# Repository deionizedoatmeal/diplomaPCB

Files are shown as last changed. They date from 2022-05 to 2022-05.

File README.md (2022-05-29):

### Bill of Materials:
Parts for the board:
| Part | Quantity | Package | Value | Link |
| --- |:---:|:---:|:---:|:---:|
| Microprocessor | 1 | QFN-56 | RP2040 | |
| 8MB SPI Flash  | 1 | SOIC-8 | | |
| NeoPixel LED | 37 | 1515 LED | SK6805-E-J | [Adafruit](https://www.adafruit.com/product/4492) |
| 7 Segement LED | 4 | LTS6760 | Common Cathode | | 
| Button Switch  | 5 | KMR2 | Momentary | |
| Schottky Diode | 4 | SOD-123 | MBR0540 | |
| Transistor | 14 | SOT-23 | | |
| Crystal | 1 | 2.5mm X 2.0mm | 12.000 MHz | |
| I2C Quad ADC | 8 | SOIC-16 | PCF8591 | |
| Quad Logic Shifter | 1 | SOIC-16 | 74AHCT125 | |
| Voltage Regulator | 4 | SOT-23-5 | AP2112K-3.3 | |
| USB-C Receptacle | 5 | SMD | | |
| USB-C Plug | 4 | SMD Edge Launch  | | [Adafruit](https://www.adafruit.com/product/4932) [Digikey](https://www.digikey.com/en/products/detail/adafruit-industries-llc/4932/13997774) |
| Resistor | 23 | 0603/1608 Metric | 300 Ω | |
| Resistor | 10 | 0603/1608 Metric | 1 kΩ | |
| Resistor | 2 | 0603/1608 Metric | 5.11 kΩ | |
| Resistor | 60 | 0603/1608 Metric | 10 kΩ | |
| Resistor | 9 | 0603/1608 Metric | 1 MΩ | |
| Resistor | 2 | 0402/1005 Metric | 27 Ω | |
| Capacitor | 45 | 0805/2012 Metric | 0.1 µF | |
| Capacitor | 20 | 0085/2012 Metric | 10 µF | |
| Capacitor | 2 | 0402/1005 Metric | 27 pF | |
| Capacitor | 10 | 0402/1005 Metric | 100 nF | |
| Capacitor | 2 | 0402/1005 Metric | 1 µF | |
| Magnets | 112 | 3mm diameter x 1mm | Neodymium | |

Parts for the game pieces (assuming 20 pieces for each nationality):
| Part | Quantity | Package | Value | Link |
| --- |:---:|:---:|:---:|:---:|
| Resistor | 20 | Through Hole | 60 kΩ | |
| Resistor | 20 | Through Hole | 25 kΩ | |
| Resistor | 20 | Through Hole | 13.4 kΩ | |
| Resistor | 20 | Through Hole | 7.5 kΩ | |
| Resistor | 20 | Through Hole | 4 kΩ | |
| Resistor | 20 | Through Hole | 1.7 kΩ | |
| Resistor | 20 | Through Hole | 0 Ω | |
| Magnets | 140 | 3mm diameter x 1mm | Neodymium | |
| Pogo Pins | 140 | anything that makes good contact with 2mm diameter pads and fits inside the piece | | [Digikey](https://www.digikey.com/en/products/detail/mill-max-manufacturing-corp/0965-0-15-20-80-14-11-0/2784013) |

### 3D Printing Pieces:

### Assembly Instructions:

### Software Install Instructions:
1) Hold down boot button on underside while plugging USB into computer.
2) When the `RPI-RP2` device shows up, copy [Adafruit's CircuitPython library](https://circuitpython.org/board/adafruit_feather_rp2040/) to the volume. 
3) Wait for the device to disappear and reappear as `CURCUITPY`, then copy all the libraries into the `lib` directory on the RP2040.
4) Finally, copy `code.py` into the `CURCUITPY` volume.

### Images
PCB

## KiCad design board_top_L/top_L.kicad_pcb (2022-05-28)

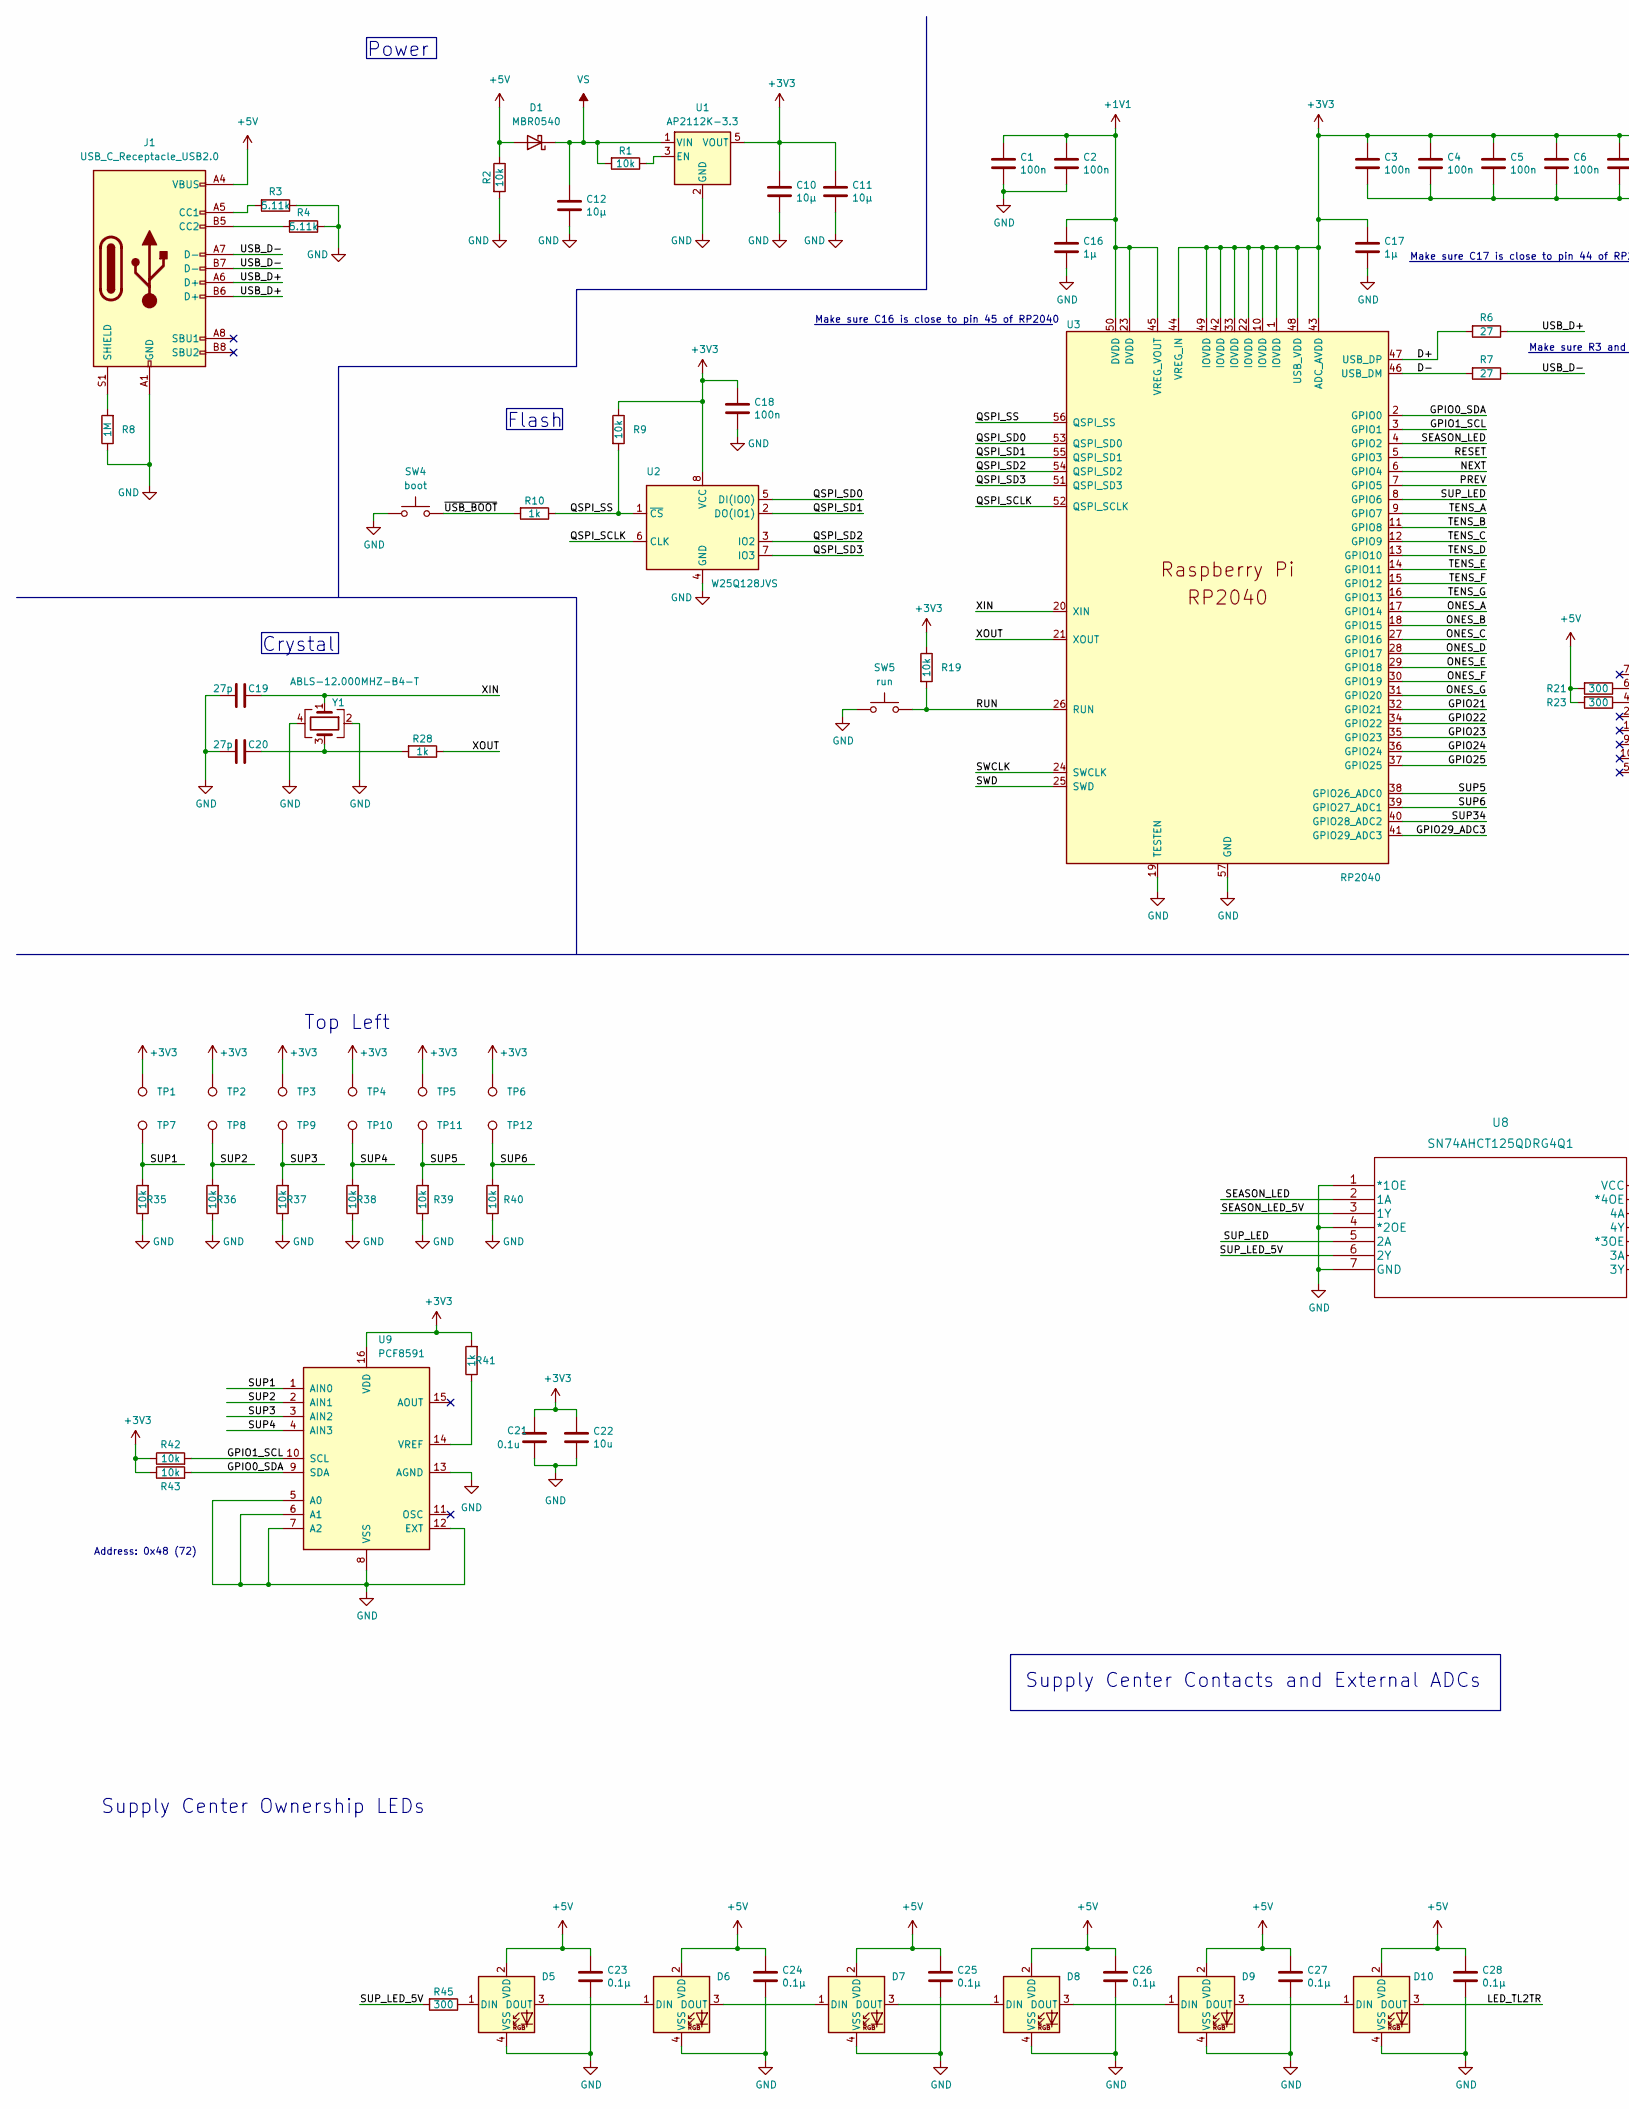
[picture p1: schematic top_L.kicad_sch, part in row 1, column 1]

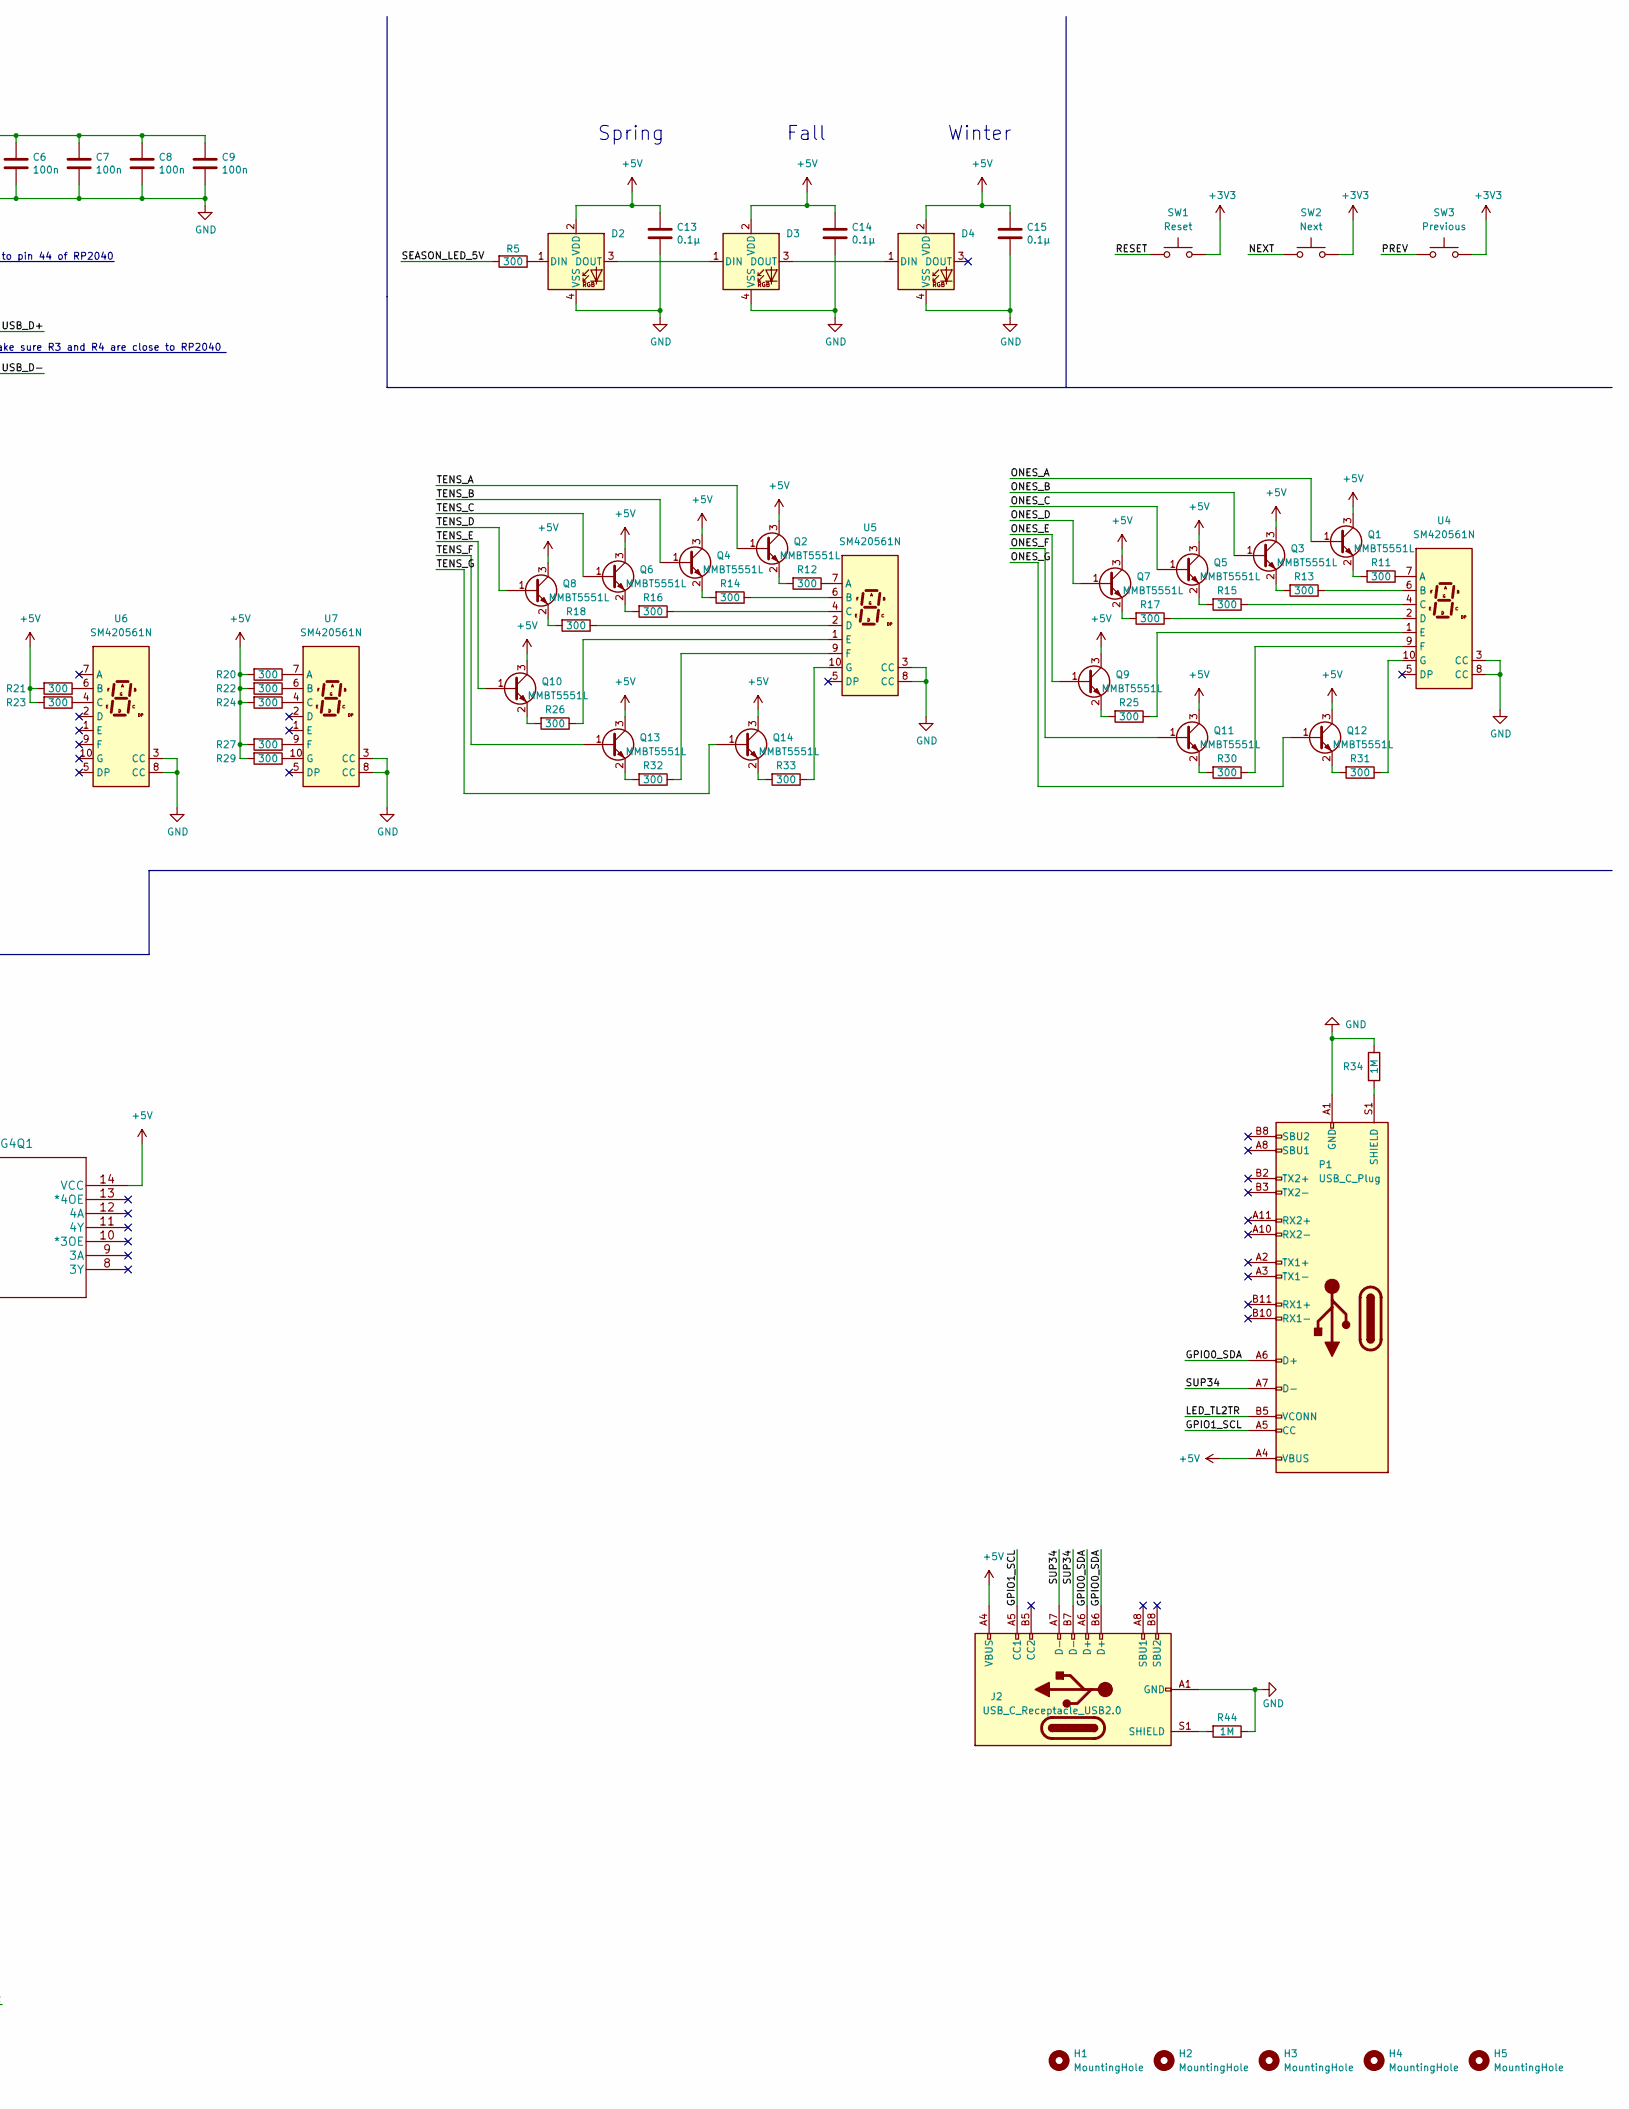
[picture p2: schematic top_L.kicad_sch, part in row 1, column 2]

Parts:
C1, C2, C3, C4, C5, C6, C7, C8, C9, C18: 100n; C_0402_1005Metric
C10, C11, C12: 10µ; C_0805_2012Metric
C13, C14, C15, C23, C24, C25, C26, C27, C28: 0.1µ; C_0805_2012Metric
C16, C17: 1µ; C_0402_1005Metric
C19, C20: 27p; C_0402_1005Metric
C21: 0.1u; C_0805_2012Metric
C22: 10u; C_0805_2012Metric
D1: MBR0540; D_SOD-123
D2, D3, D4, D5, D6, D7, D8, D9, D10: SK6805-EC
H1, H2, H3, H4, H5: MountingHole; MountingHole_2.2mm_M2
J1, J2: USB_C_Receptacle_USB2.0; USB_C_Receptacle_HRO_TYPE-C-31-M-12
P1: USB_C_Plug; USB_C_Plug_edge_launch
Q1, Q2, Q3, Q4, Q5, Q6, Q7, Q8, Q9, Q10, Q11, Q12, Q13, Q14: MMBT5551L; SOT-23
R1, R2, R9, R19, R35, R36, R37, R38, R39, R40, R42, R43: 10k; R_0603_1608Metric
R3, R4: 5.11k; R_0603_1608Metric
R5, R11, R12, R13, R14, R15, R16, R17, R18, R20, R21, R22, R23, R24, R25, R26, R27, R29, R30, R31, R32, R33, R45: 300; R_0603_1608Metric
R6, R7: 27; R_0402_1005Metric
R8, R34, R44: 1M; R_0603_1608Metric
R10, R28, R41: 1k; R_0603_1608Metric
SW1: Reset; SW_Push_1P1T_NO_CK_KMR2
SW2: Next; SW_Push_1P1T_NO_CK_KMR2
SW3: Previous; SW_Push_1P1T_NO_CK_KMR2
SW4: boot; SW_Push_1P1T_NO_CK_KMR2
SW5: run; SW_Push_1P1T_NO_CK_KMR2
TP1, TP2, TP3, TP4, TP5, TP6, TP7, TP8, TP9, TP10, TP11, TP12: TestPoint; TestPoint_Pad_D2.0mm
U1: AP2112K-3.3; SOT-23-5
U2: W25Q128JVS; SOIC-8_5.23x5.23mm_P1.27mm
U3: RP2040; RP2040-QFN-56
U4, U5, U6, U7: SM420561N; 7SegmentLED_LTS6760_LTS6780
U8: SN74AHCT125QDRG4Q1
U9: PCF8591; SOIC-16W_7.5x10.3mm_P1.27mm
Y1: ABLS-12.000MHZ-B4-T; Crystal_SMD_3225-4Pin_3.2x2.5mm

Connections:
+1V1: C1.1, C2.1, C16.1, U3.23 (DVDD), U3.45 (VREG_VOUT), U3.50 (DVDD)
+3V3: C3.1, C4.1, C5.1, C6.1, C7.1, C8.1, C9.1, C10.1, C11.1, C17.1, C18.1, C21.1, C22.1, R9.1, R19.1, R41.2, R42.1, R43.1, SW1.2, SW2.2, SW3.2, TP1.1, TP2.1, TP3.1, TP4.1, TP5.1, TP6.1, U1.5 (VOUT), U2.8 (VCC), U3.1 (IOVDD), U3.10 (IOVDD), U3.22 (IOVDD), U3.33 (IOVDD), U3.42 (IOVDD), U3.43 (ADC_AVDD), U3.44 (VREG_IN), U3.48 (USB_VDD), U3.49 (IOVDD), U9.16 (VDD)
+5V: C13.1, C14.1, C15.1, C23.1, C24.1, C25.1, C26.1, C27.1, C28.1, D1.2 (A), D2.2 (VDD), D3.2 (VDD), D4.2 (VDD), D5.2 (VDD), D6.2 (VDD), D7.2 (VDD), D8.2 (VDD), D9.2 (VDD), D10.2 (VDD), J1.A4 (VBUS), J1.A9 (VBUS), J1.B4 (VBUS), J1.B9 (VBUS), J2.A4 (VBUS), J2.A9 (VBUS), J2.B4 (VBUS), J2.B9 (VBUS), P1.A4 (VBUS), P1.A9 (VBUS), P1.B4 (VBUS), P1.B9 (VBUS), Q1.3 (C), Q2.3 (C), Q3.3 (C), Q4.3 (C), Q5.3 (C), Q6.3 (C), Q7.3 (C), Q8.3 (C), Q9.3 (C), Q10.3 (C), Q11.3 (C), Q12.3 (C), Q13.3 (C), Q14.3 (C), R2.1, R20.2, R21.2, R22.2, R23.2, R24.2, R27.2, R29.2, U8.14 (VCC)
/D+: R6.2, U3.47 (USB_DP)
/D-: R7.2, U3.46 (USB_DM)
/GPIO0_SDA: J2.A6 (D+), J2.B6 (D+), P1.A6 (D+), R43.2, U3.2 (GPIO0), U9.9 (SDA)
/GPIO1_SCL: J2.A5 (CC1), P1.A5 (CC), R42.2, U3.3 (GPIO1), U9.10 (SCL)
/GPIO21: U3.32 (GPIO21)
/GPIO22: U3.34 (GPIO22)
/GPIO23: U3.35 (GPIO23)
/GPIO24: U3.36 (GPIO24)
/GPIO25: U3.37 (GPIO25)
/GPIO29_ADC3: U3.41 (GPIO29_ADC3)
/LED_TL2TR: D10.3 (DOUT), P1.B5 (VCONN)
/NEXT: SW2.1, U3.6 (GPIO4)
/ONES_A: Q1.1 (B), U3.17 (GPIO14)
/ONES_B: Q3.1 (B), U3.18 (GPIO15)
/ONES_C: Q5.1 (B), U3.27 (GPIO16)
/ONES_D: Q7.1 (B), U3.28 (GPIO17)
/ONES_E: Q9.1 (B), U3.29 (GPIO18)
/ONES_F: Q11.1 (B), U3.30 (GPIO19)
/ONES_G: Q12.1 (B), U3.31 (GPIO20)
/PREV: SW3.1, U3.7 (GPIO5)
/QSPI_SCLK: U2.6 (CLK), U3.52 (QSPI_SCLK)
/QSPI_SD0: U2.5 (DI(IO0)), U3.53 (QSPI_SD0)
/QSPI_SD1: U2.2 (DO(IO1)), U3.55 (QSPI_SD1)
/QSPI_SD2: U2.3 (IO2), U3.54 (QSPI_SD2)
/QSPI_SD3: U2.7 (IO3), U3.51 (QSPI_SD3)
/QSPI_SS: R9.2, R10.1, U2.1 (~CS), U3.56 (QSPI_SS)
/RESET: SW1.1, U3.5 (GPIO3)
/RUN: R19.2, SW5.2, U3.26 (RUN)
/SEASON_LED: U3.4 (GPIO2), U8.2 (1A)
/SEASON_LED_5V: R5.2, U8.3 (1Y)
/SUP1: R35.2, TP7.1, U9.1 (AIN0)
/SUP2: R36.2, TP8.1, U9.2 (AIN1)
/SUP3: R37.2, TP9.1, U9.3 (AIN2)
/SUP4: R38.2, TP10.1, U9.4 (AIN3)
/SUP5: R39.2, TP11.1, U3.38 (GPIO26_ADC0)
/SUP6: R40.2, TP12.1, U3.39 (GPIO27_ADC1)
/SUP34: J2.A7 (D-), J2.B7 (D-), P1.A7 (D-), U3.40 (GPIO28_ADC2)
/SUP_LED: U3.8 (GPIO6), U8.5 (2A)
/SUP_LED_5V: R45.2, U8.6 (2Y)
/SWCLK: U3.24 (SWCLK)
/SWD: U3.25 (SWD)
/TENS_A: Q2.1 (B), U3.9 (GPIO7)
/TENS_B: Q4.1 (B), U3.11 (GPIO8)
/TENS_C: Q6.1 (B), U3.12 (GPIO9)
/TENS_D: Q8.1 (B), U3.13 (GPIO10)
/TENS_E: Q10.1 (B), U3.14 (GPIO11)
/TENS_F: Q13.1 (B), U3.15 (GPIO12)
/TENS_G: Q14.1 (B), U3.16 (GPIO13)
/USB_D+: J1.A6 (D+), J1.B6 (D+), R6.1
/USB_D-: J1.A7 (D-), J1.B7 (D-), R7.1
/XIN: C19.1, U3.20 (XIN), Y1.1
/XOUT: R28.1, U3.21 (XOUT)
/~USB_BOOT: R10.2, SW4.2
GND: C1.2, C2.2, C3.2, C4.2, C5.2, C6.2, C7.2, C8.2, C9.2, C10.2, C11.2, C12.2, C13.2, C14.2, C15.2, C16.2, C17.2, C18.2, C19.2, C20.2, C21.2, C22.2, C23.2, C24.2, C25.2, C26.2, C27.2, C28.2, D2.4 (VSS), D3.4 (VSS), D4.4 (VSS), D5.4 (VSS), D6.4 (VSS), D7.4 (VSS), D8.4 (VSS), D9.4 (VSS), D10.4 (VSS), J1.A1 (GND), J1.A12 (GND), J1.B1 (GND), J1.B12 (GND), J2.A1 (GND), J2.A12 (GND), J2.B1 (GND), J2.B12 (GND), P1.A1 (GND), P1.A12 (GND), P1.B1 (GND), P1.B12 (GND), R2.2, R3.1, R4.1, R8.1, R34.1, R35.1, R36.1, R37.1, R38.1, R39.1, R40.1, R44.1, SW4.1, SW5.1, U1.2 (GND), U2.4 (GND), U3.19 (TESTEN), U3.57 (GND), U4.3 (CC), U4.8 (CC), U5.3 (CC), U5.8 (CC), U6.3 (CC), U6.8 (CC), U7.3 (CC), U7.8 (CC), U8.1 (*1OE), U8.4 (*2OE), U8.7 (GND), U9.5 (A0), U9.6 (A1), U9.7 (A2), U9.8 (VSS), U9.12 (EXT), U9.13 (AGND), Y1.2, Y1.4
unnamed: C20.1, R28.2, Y1.3
unnamed: D2.1 (DIN), R5.1
unnamed: D2.3 (DOUT), D3.1 (DIN)
unnamed: D3.3 (DOUT), D4.1 (DIN)
unnamed: D5.1 (DIN), R45.1
unnamed: D5.3 (DOUT), D6.1 (DIN)
unnamed: D6.3 (DOUT), D7.1 (DIN)
unnamed: D7.3 (DOUT), D8.1 (DIN)
unnamed: D8.3 (DOUT), D9.1 (DIN)
unnamed: D9.3 (DOUT), D10.1 (DIN)
unnamed: J1.A5 (CC1), R3.2
unnamed: J1.B5 (CC2), R4.2
unnamed: J1.S1 (SHIELD), R8.2
unnamed: J2.S1 (SHIELD), R44.2
unnamed: P1.S1 (SHIELD), R34.2
unnamed: Q1.2 (E), R11.2
unnamed: Q2.2 (E), R12.2
unnamed: Q3.2 (E), R13.2
unnamed: Q4.2 (E), R14.2
unnamed: Q5.2 (E), R15.2
unnamed: Q6.2 (E), R16.2
unnamed: Q7.2 (E), R17.2
unnamed: Q8.2 (E), R18.2
unnamed: Q9.2 (E), R25.2
unnamed: Q10.2 (E), R26.2
unnamed: Q11.2 (E), R30.2
unnamed: Q12.2 (E), R31.2
unnamed: Q13.2 (E), R32.2
unnamed: Q14.2 (E), R33.2
unnamed: R1.1, U1.3 (EN)
unnamed: R11.1, U4.7 (A)
unnamed: R12.1, U5.7 (A)
unnamed: R13.1, U4.6 (B)
unnamed: R14.1, U5.6 (B)
unnamed: R15.1, U4.4 (C)
unnamed: R16.1, U5.4 (C)
unnamed: R17.1, U4.2 (D)
unnamed: R18.1, U5.2 (D)
unnamed: R20.1, U7.7 (A)
unnamed: R21.1, U6.6 (B)
unnamed: R22.1, U7.6 (B)
unnamed: R23.1, U6.4 (C)
unnamed: R24.1, U7.4 (C)
unnamed: R25.1, U4.1 (E)
unnamed: R26.1, U5.1 (E)
unnamed: R27.1, U7.9 (F)
unnamed: R29.1, U7.10 (G)
unnamed: R30.1, U4.9 (F)
unnamed: R31.1, U4.10 (G)
unnamed: R32.1, U5.9 (F)
unnamed: R33.1, U5.10 (G)
unnamed: R41.1, U9.14 (VREF)
VS: C12.1, D1.1 (K), R1.2, U1.1 (VIN)

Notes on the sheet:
Winter
Crystal
Make sure C16 is close to pin 45 of RP2040
Address: 0x48 (72)
Top Left
Make sure C17 is close to pin 44 of RP2040
Supply Center Contacts and External ADCs
Supply Center Ownership LEDs
Spring
Fall
Make sure R3 and R4 are close to RP2040
Power
Flash

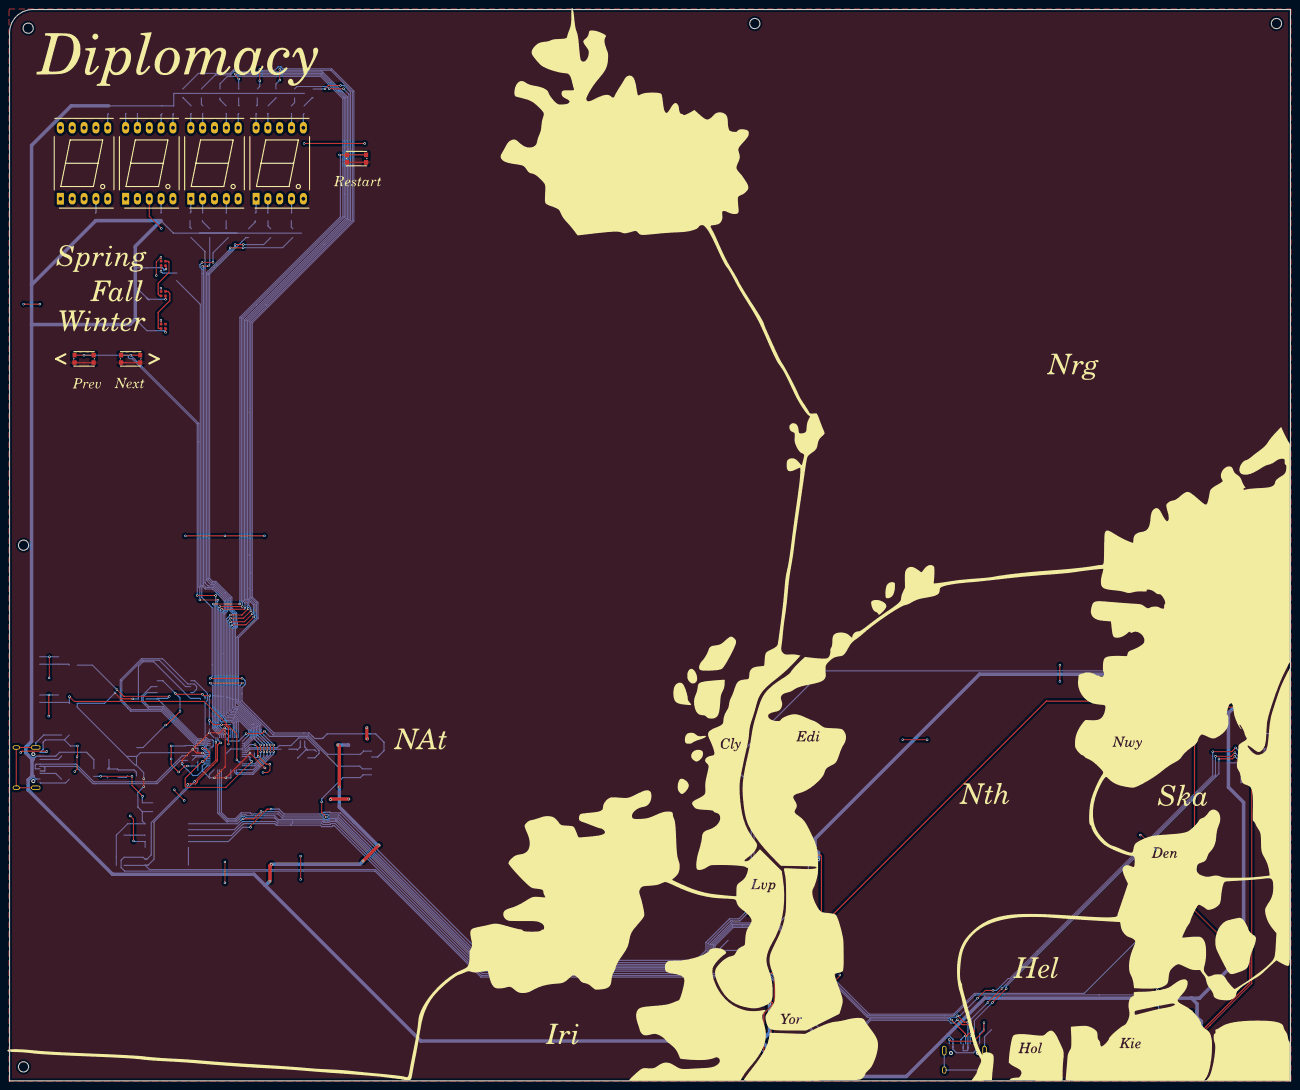
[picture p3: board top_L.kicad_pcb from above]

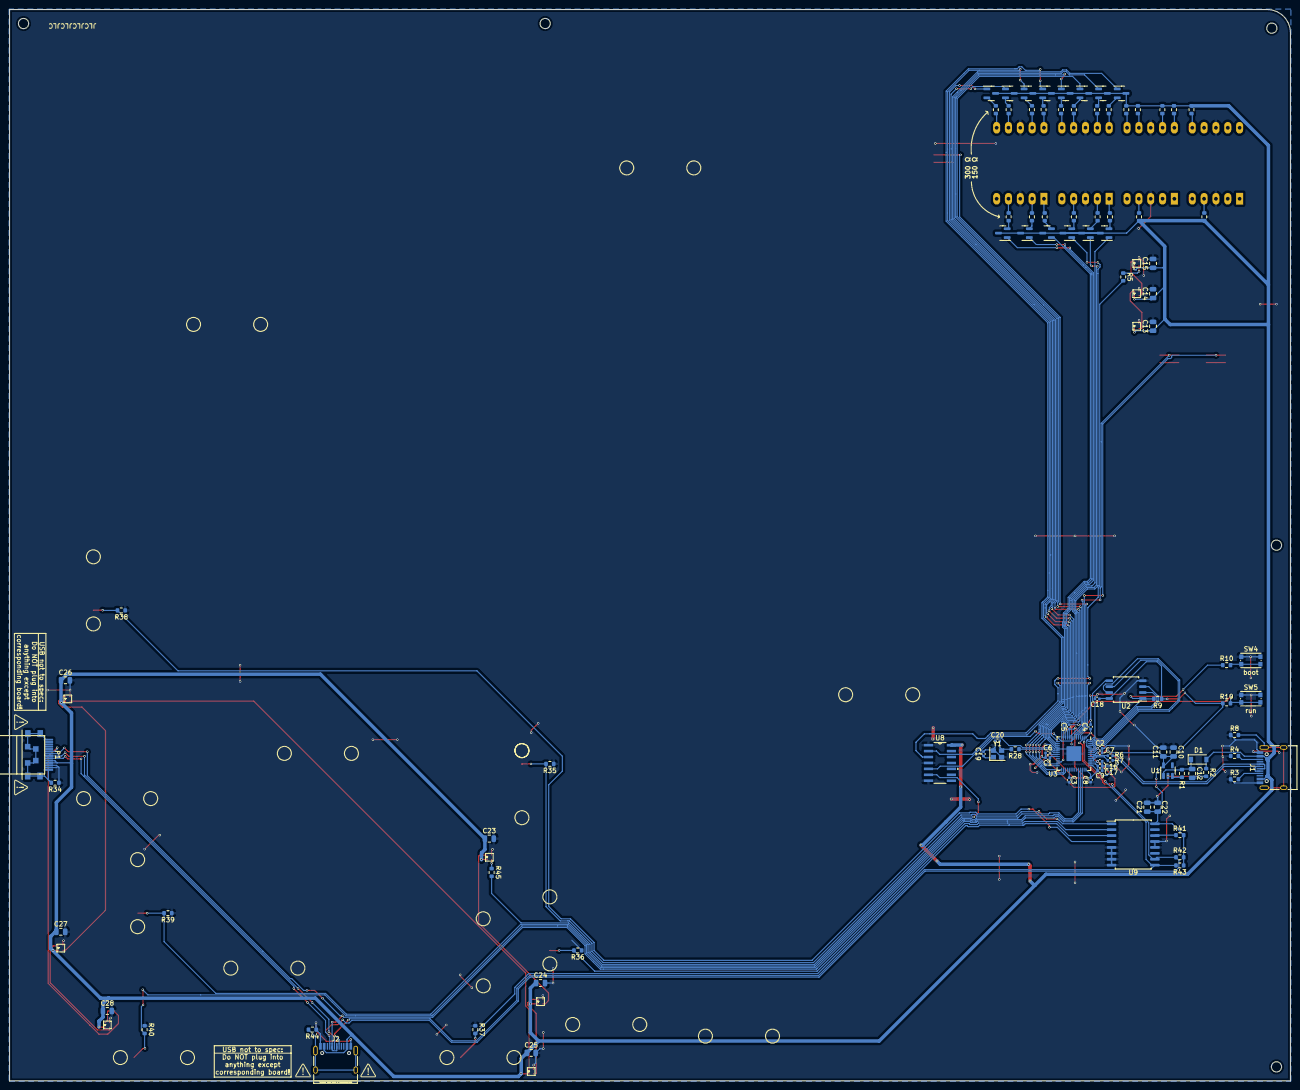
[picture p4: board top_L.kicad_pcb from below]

Board: 2 copper layers, 275.0 x 230.0 mm, 132 parts (99 on the bottom side), 102 nets.

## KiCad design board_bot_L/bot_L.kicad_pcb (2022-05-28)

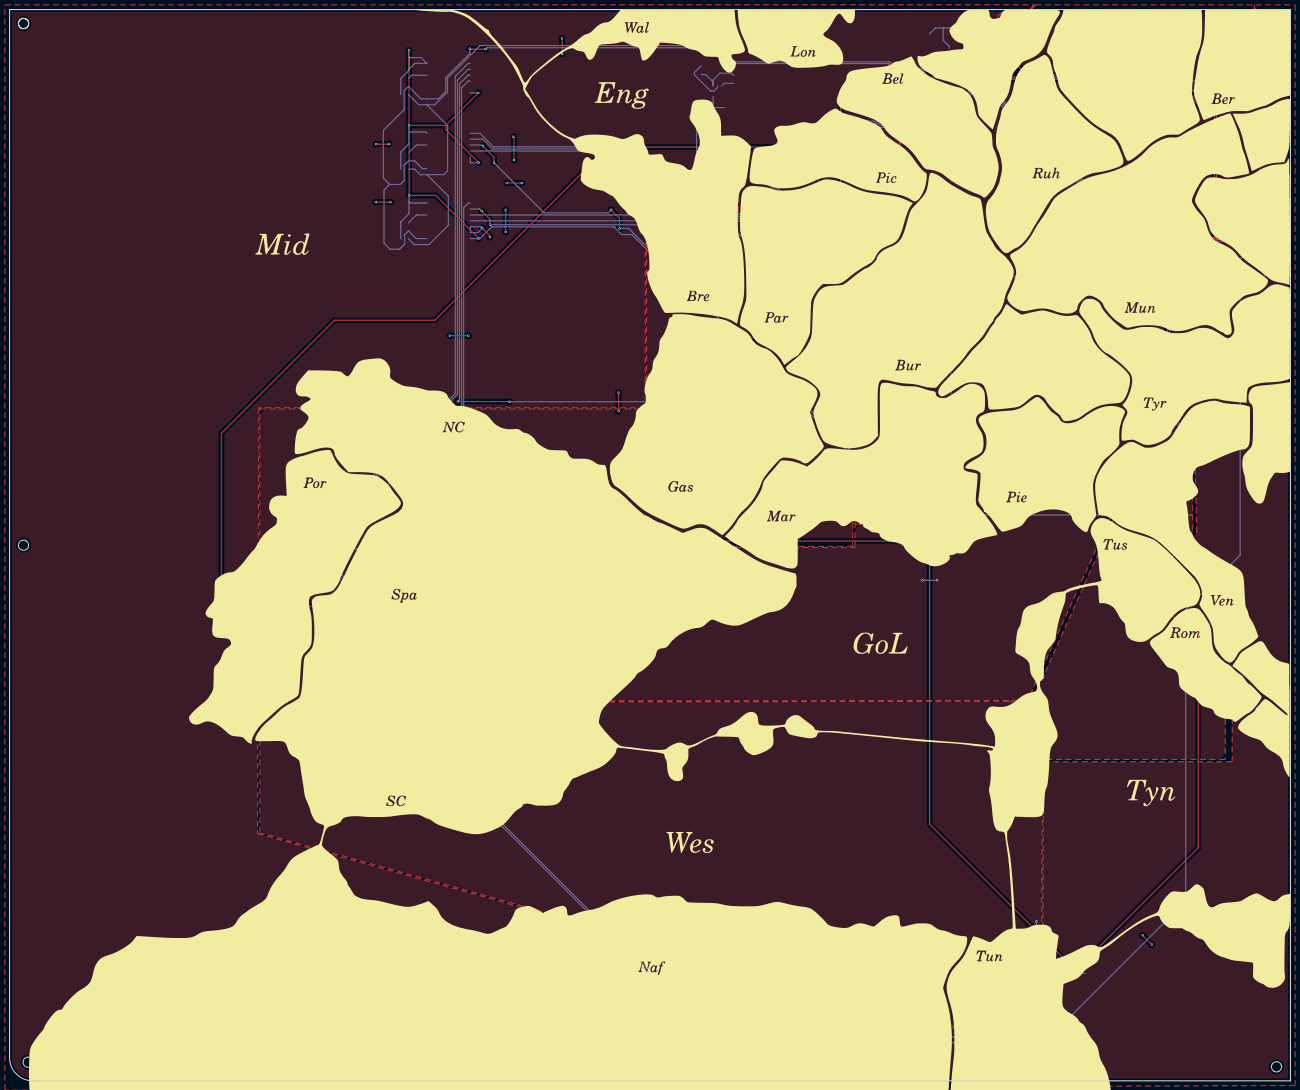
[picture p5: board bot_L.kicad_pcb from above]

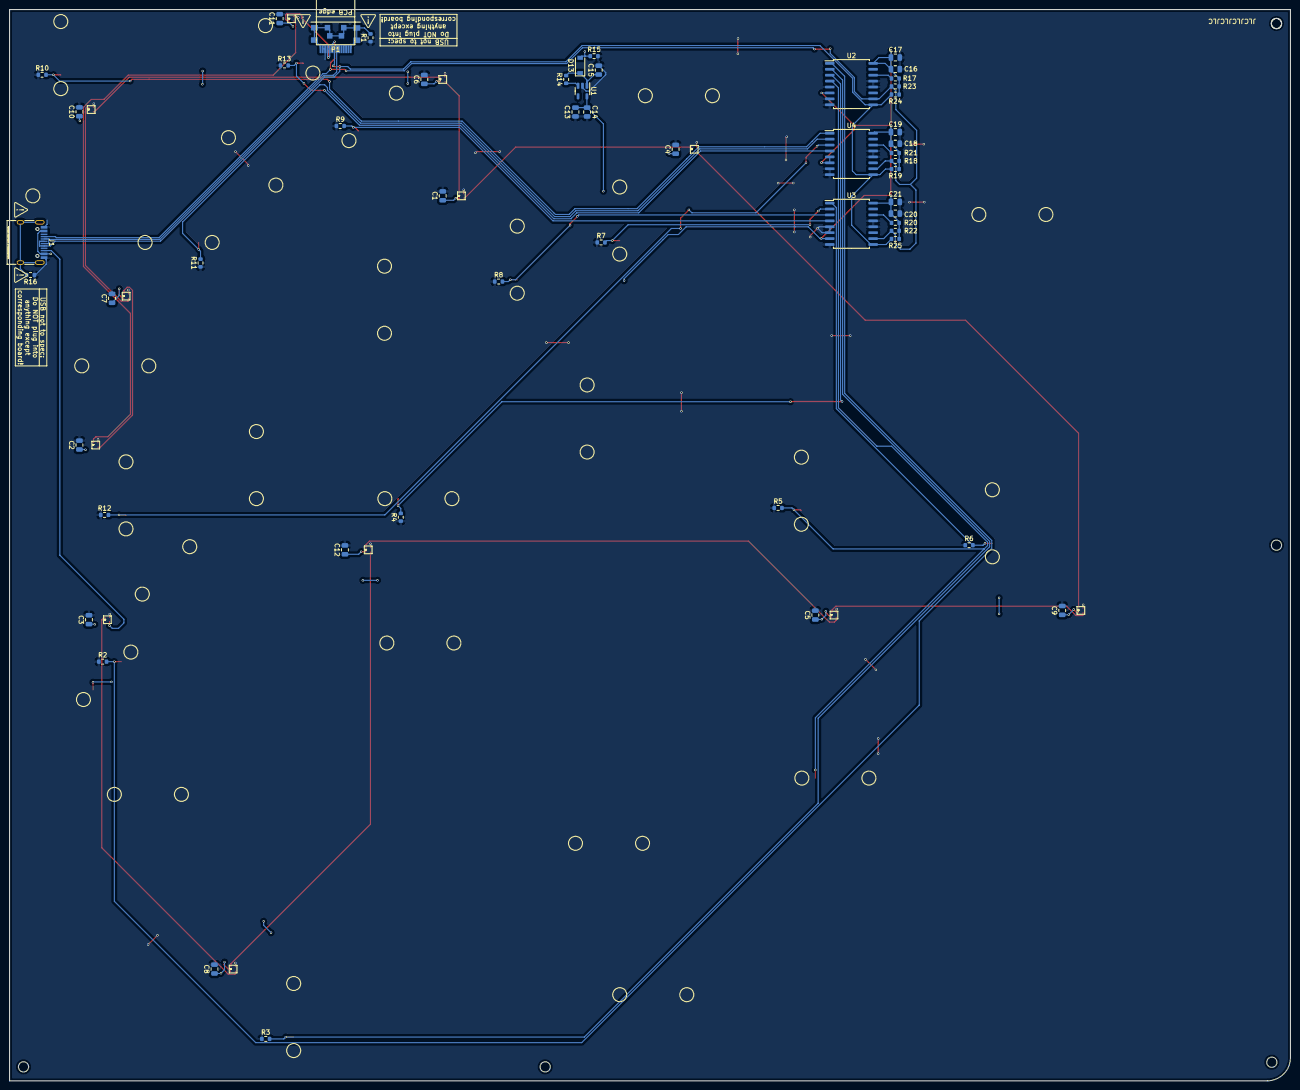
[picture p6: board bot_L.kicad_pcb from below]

Board: 2 copper layers, 275.0 x 230.0 mm, 96 parts (53 on the bottom side), 37 nets.

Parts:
C1, C2, C3, C4, C5, C6, C7, C8, C9, C10, C11, C12: 0.1µ; C_0805_2012Metric
C13, C14, C15: 10µ; C_0805_2012Metric
C16, C18, C20: 0.1u; C_0805_2012Metric
C17, C19, C21: 10u; C_0805_2012Metric
D1, D2, D3, D4, D5, D6, D7, D8, D9, D10, D11, D12: SK6805-EC
D13: MBR0540; D_SOD-123
H1, H2, H3, H4, H5: MountingHole; MountingHole_2.2mm_M2
J1: USB_C_Receptacle_USB2.0; USB_C_Receptacle_HRO_TYPE-C-31-M-12
P1: USB_C_Plug; USB_C_Plug_edge_launch
R1, R16: 1M; R_0603_1608Metric
R2, R3, R4, R5, R6, R7, R8, R9, R10, R11, R12, R13, R14, R15, R18, R19, R22, R23, R24, R25: 10k; R_0603_1608Metric
R17, R20, R21: 1k; R_0603_1608Metric
TP1, TP2, TP3, TP4, TP5, TP6, TP7, TP8, TP9, TP10, TP11, TP12, TP13, TP14, TP15, TP16, TP17, TP18, TP19, TP20, TP21, TP22, TP23, TP24, TP25, TP26: TestPoint; TestPoint_Pad_D2.0mm
U1: AP2112K-3.3; SOT-23-5
U2, U3, U4: PCF8591; SOIC-16W_7.5x10.3mm_P1.27mm

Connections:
+3V3: C13.1, C14.1, C16.1, C17.1, C18.1, C19.1, C20.1, C21.1, R17.2, R18.1, R19.1, R20.2, R21.2, R22.1, R23.1, R24.1, R25.1, TP1.1, TP2.1, TP3.1, TP4.1, TP5.1, TP6.1, TP7.1, TP8.1, TP9.1, TP10.1, TP11.1, TP12.1, TP25.1, U1.5 (VOUT), U2.6 (A1), U2.16 (VDD), U3.7 (A2), U3.16 (VDD), U4.5 (A0), U4.6 (A1), U4.16 (VDD)
+5V: C1.1, C2.1, C3.1, C4.1, C5.1, C6.1, C7.1, C8.1, C9.1, C10.1, C11.1, C12.1, D1.2 (VDD), D2.2 (VDD), D3.2 (VDD), D4.2 (VDD), D5.2 (VDD), D6.2 (VDD), D7.2 (VDD), D8.2 (VDD), D9.2 (VDD), D10.2 (VDD), D11.2 (VDD), D12.2 (VDD), D13.2 (A), J1.A4 (VBUS), J1.A9 (VBUS), J1.B4 (VBUS), J1.B9 (VBUS), P1.A4 (VBUS), P1.B9 (VBUS), R15.1
/GPIO0_SDA: J1.A6 (D+), J1.B6 (D+), P1.A6 (D+), R19.2, R24.2, R25.2, U2.9 (SDA), U3.9 (SDA), U4.9 (SDA)
/GPIO1_SCL: J1.A5 (CC1), P1.A5 (CC), R18.2, R22.2, R23.2, U2.10 (SCL), U3.10 (SCL), U4.10 (SCL)
/LED_BR2BL: D1.1 (DIN), J1.B5 (CC2)
/SUP10: R2.2, TP13.1, U2.1 (AIN0)
/SUP11: R3.2, TP14.1, U2.2 (AIN1)
/SUP12: R4.2, TP15.1, U2.3 (AIN2)
/SUP13: R5.2, TP16.1, TP26.1, U2.4 (AIN3)
/SUP14: R6.2, TP17.1, U3.1 (AIN0)
/SUP15: R7.2, TP18.1, U3.2 (AIN1)
/SUP16: R8.2, TP19.1, U3.3 (AIN2)
/SUP17: R9.2, TP20.1, U3.4 (AIN3)
/SUP18: R10.2, TP21.1, U4.1 (AIN0)
/SUP19: R11.2, TP22.1, U4.2 (AIN1)
/SUP20: R12.2, TP23.1, U4.3 (AIN2)
/SUP21: R13.2, TP24.1, U4.4 (AIN3)
/SUP34: J1.A7 (D-), J1.B7 (D-), P1.A7 (D-)
GND: C1.2, C2.2, C3.2, C4.2, C5.2, C6.2, C7.2, C8.2, C9.2, C10.2, C11.2, C12.2, C13.2, C14.2, C15.2, C16.2, C17.2, C18.2, C19.2, C20.2, C21.2, D1.4 (VSS), D2.4 (VSS), D3.4 (VSS), D4.4 (VSS), D5.4 (VSS), D6.4 (VSS), D7.4 (VSS), D8.4 (VSS), D9.4 (VSS), D10.4 (VSS), D11.4 (VSS), D12.4 (VSS), J1.A1 (GND), J1.A12 (GND), J1.B1 (GND), J1.B12 (GND), P1.A1 (GND), P1.B12 (GND), R1.1, R2.1, R3.1, R4.1, R5.1, R6.1, R7.1, R8.1, R9.1, R10.1, R11.1, R12.1, R13.1, R15.2, R16.1, U1.2 (GND), U2.5 (A0), U2.7 (A2), U2.8 (VSS), U2.12 (EXT), U2.13 (AGND), U3.5 (A0), U3.6 (A1), U3.8 (VSS), U3.12 (EXT), U3.13 (AGND), U4.7 (A2), U4.8 (VSS), U4.12 (EXT), U4.13 (AGND)
unnamed: D1.3 (DOUT), D2.1 (DIN)
unnamed: D2.3 (DOUT), D3.1 (DIN)
unnamed: D3.3 (DOUT), D4.1 (DIN)
unnamed: D4.3 (DOUT), D5.1 (DIN)
unnamed: D5.3 (DOUT), D6.1 (DIN)
unnamed: D6.3 (DOUT), D7.1 (DIN)
unnamed: D7.3 (DOUT), D8.1 (DIN)
unnamed: D8.3 (DOUT), D9.1 (DIN)
unnamed: D9.3 (DOUT), D10.1 (DIN)
unnamed: D10.3 (DOUT), D11.1 (DIN)
unnamed: D11.3 (DOUT), D12.1 (DIN)
unnamed: J1.S1 (SHIELD), R16.2
unnamed: P1.S1 (SHIELD), R1.2
unnamed: R14.1, U1.3 (EN)
unnamed: R17.1, U2.14 (VREF)
unnamed: R20.1, U3.14 (VREF)
unnamed: R21.1, U4.14 (VREF)
VS: C15.1, D13.1 (K), R14.2, U1.1 (VIN)

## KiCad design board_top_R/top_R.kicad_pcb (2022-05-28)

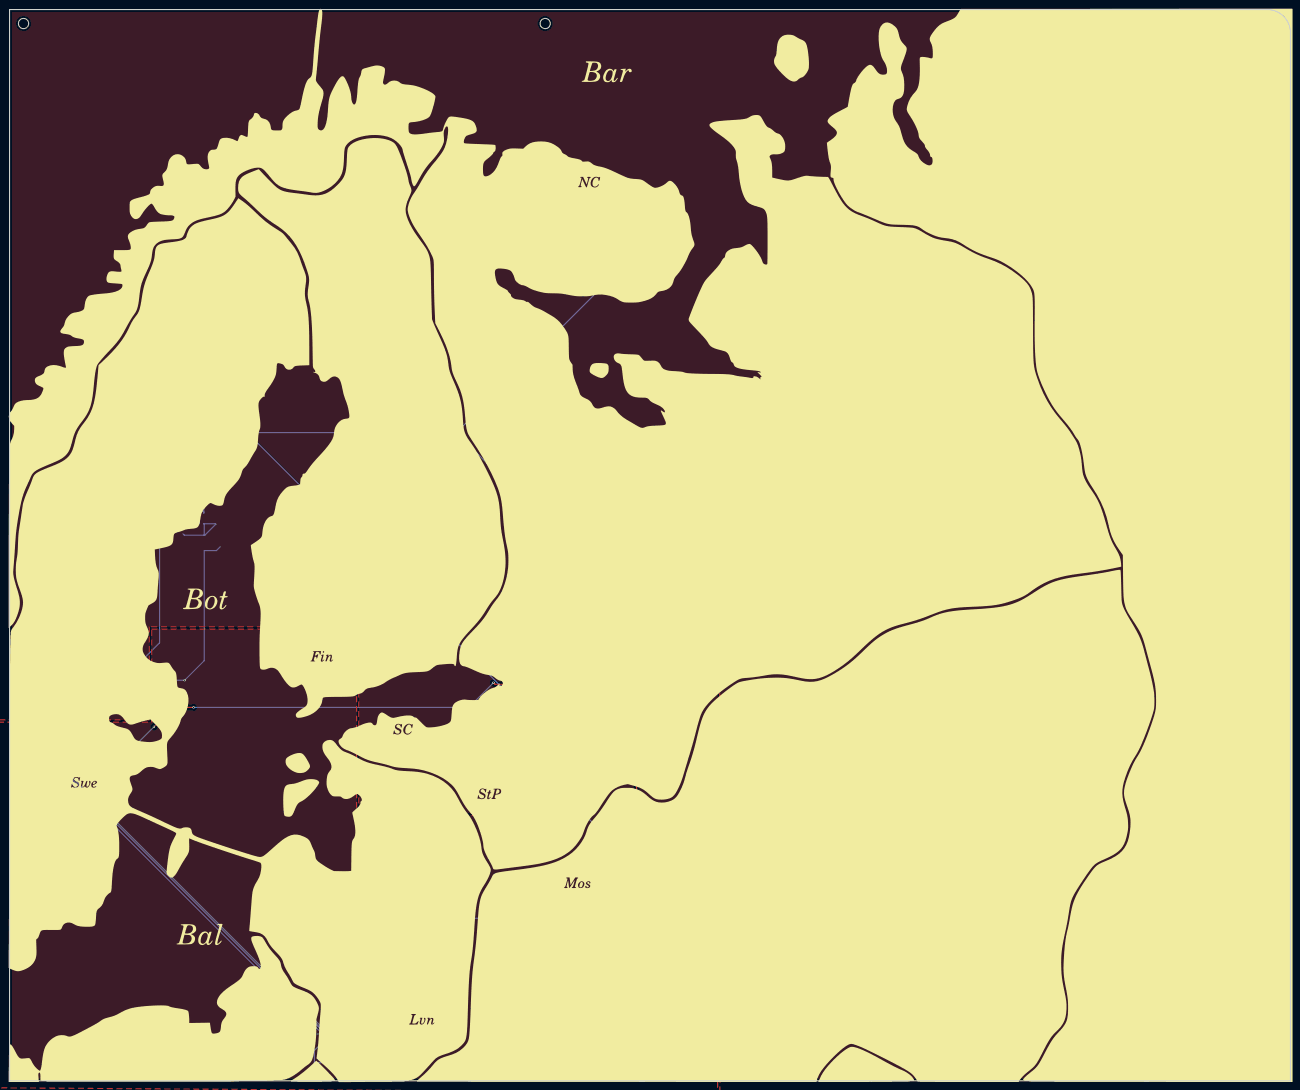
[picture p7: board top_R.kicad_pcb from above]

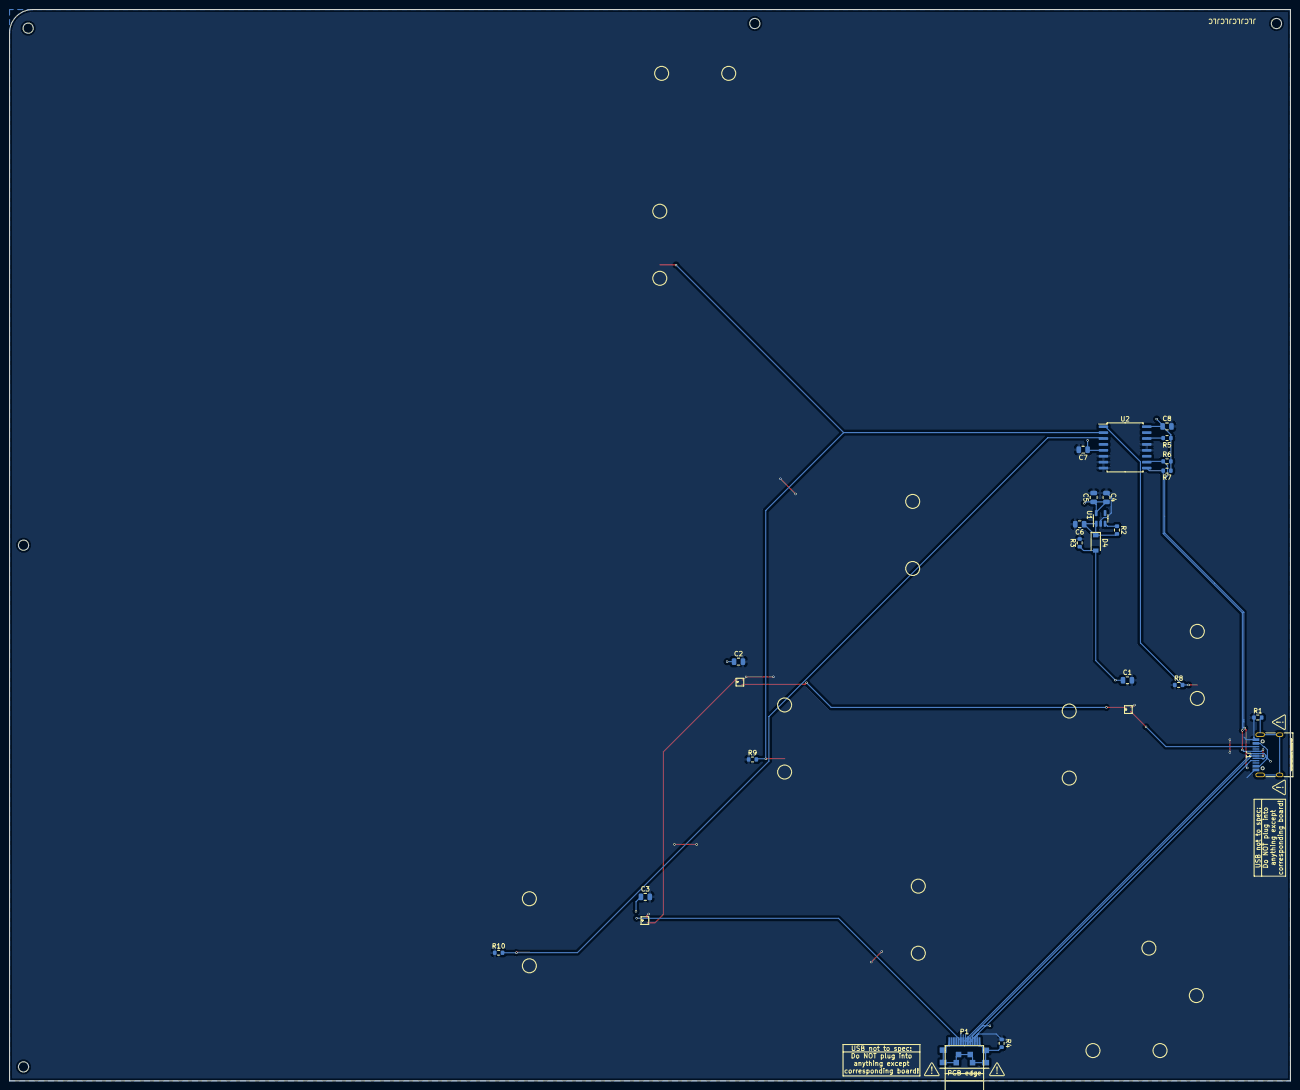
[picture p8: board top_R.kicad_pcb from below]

Board: 2 copper layers, 275.0 x 230.0 mm, 39 parts (23 on the bottom side), 18 nets.

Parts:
C1, C2, C3: 0.1µ; C_0805_2012Metric
C4, C5, C6: 10µ; C_0805_2012Metric
C7: 0.1u; C_0805_2012Metric
C8: 10u; C_0805_2012Metric
D1, D2, D3: SK6805-EC
D4: MBR0540; D_SOD-123
H1, H2, H3, H4, H5: MountingHole; MountingHole_2.2mm_M2
J1: USB_C_Receptacle_USB2.0; USB_C_Receptacle_HRO_TYPE-C-31-M-12
P1: USB_C_Plug; USB_C_Plug_edge_launch
R1, R4: 1M; R_0603_1608Metric
R2, R3, R6, R7, R8, R9, R10: 10k; R_0603_1608Metric
R5: 1k; R_0603_1608Metric
TP1, TP2, TP3, TP4, TP5, TP6, TP7, TP8: TestPoint; TestPoint_Pad_D2.0mm
U1: AP2112K-3.3; SOT-23-5
U2: PCF8591; SOIC-16W_7.5x10.3mm_P1.27mm

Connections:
+3V3: C4.1, C5.1, C7.1, C8.1, R5.2, R6.1, R7.1, TP1.1, TP3.1, TP4.1, TP5.1, U1.5 (VOUT), U2.5 (A0), U2.16 (VDD)
+5V: C1.1, C2.1, C3.1, D1.2 (VDD), D2.2 (VDD), D3.2 (VDD), D4.2 (A), J1.A4 (VBUS), J1.A9 (VBUS), J1.B4 (VBUS), J1.B9 (VBUS), P1.A4 (VBUS), P1.B9 (VBUS), R3.1
/GPIO0_SDA: J1.A6 (D+), J1.B6 (D+), P1.A6 (D+), R7.2, U2.9 (SDA)
/GPIO1_SCL: J1.A5 (CC1), P1.A5 (CC), R6.2, U2.10 (SCL)
/LED_TL2TR: D1.1 (DIN), J1.B5 (CC2)
/LED_TR2BR: D3.3 (DOUT), P1.B5 (VCONN)
/SUP7: R8.2, TP6.1, U2.1 (AIN0)
/SUP8: R9.2, TP2.1, TP7.1, U2.2 (AIN1)
/SUP9: R10.2, TP8.1, U2.3 (AIN2)
/SUP34: J1.A7 (D-), J1.B7 (D-), P1.A7 (D-)
GND: C1.2, C2.2, C3.2, C4.2, C5.2, C6.2, C7.2, C8.2, D1.4 (VSS), D2.4 (VSS), D3.4 (VSS), J1.A1 (GND), J1.A12 (GND), J1.B1 (GND), J1.B12 (GND), P1.A1 (GND), P1.B12 (GND), R1.1, R3.2, R4.1, R8.1, R9.1, R10.1, U1.2 (GND), U2.6 (A1), U2.7 (A2), U2.8 (VSS), U2.12 (EXT), U2.13 (AGND)
unnamed: D1.3 (DOUT), D2.1 (DIN)
unnamed: D2.3 (DOUT), D3.1 (DIN)
unnamed: J1.S1 (SHIELD), R1.2
unnamed: P1.S1 (SHIELD), R4.2
unnamed: R2.1, U1.3 (EN)
unnamed: R5.1, U2.14 (VREF)
VS: C6.1, D4.1 (K), R2.2, U1.1 (VIN)

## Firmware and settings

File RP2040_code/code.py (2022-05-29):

# diplomaPCB firmware v0.8
# GPLv3 applies
# ian k. bania, may 2022

#################
### LIBRARIES ###
#################
import board
import busio
import neopixel
import digitalio
import analogio
import adafruit_pcf8591.pcf8591 as PCF
from adafruit_pcf8591.analog_in import AnalogIn
from adafruit_pcf8591.analog_out import AnalogOut
from random import randrange

#################
### FUNCTIONS ###
#################
def set_7seg_disp(first_digit: int, second_digit: int):
    """writes the proper year to the 7 seg displays"""
    # set the component LEDs of 7 segment display
    if second_digit == 0:
        ones_A = True
        ones_B = True
        ones_C = False
        ones_D = True
        ones_E = True
        ones_F = True
        ones_G = False 
    
    if second_digit == 1:
        ones_A = False 
        ones_B = True
        ones_C = True
        ones_D = False
        ones_E = False
        ones_F = False
        ones_G = False 

    if second_digit == 2:
        ones_A = True 
        ones_B = True
        ones_C = False
        ones_D = True
        ones_E = True
        ones_F = False
        ones_G = True 

    if second_digit == 3:
        ones_A = True 
        ones_B = True
        ones_C = True
        ones_D = True
        ones_E = False
        ones_F = False
        ones_G = True 

    if second_digit == 4:
        ones_A = True 
        ones_B = True
        ones_C = True
        ones_D = False
        ones_E = False
        ones_F = False
        ones_G = True 

    if second_digit == 5:
        ones_A = True 
        ones_B = False
        ones_C = True
        ones_D = True
        ones_E = False
        ones_F = True
        ones_G = True 

    if second_digit == 6:
        ones_A = True 
        ones_B = False
        ones_C = True
        ones_D = True
        ones_E = True
        ones_F = True
        ones_G = True 

    if second_digit == 7:
        ones_A = True 
        ones_B = True
        ones_C = True
        ones_D = False
        ones_E = False
        ones_F = False
        ones_G = False

    if second_digit == 8:
        ones_A = True 
        ones_B = True
        ones_C = True
        ones_D = True
        ones_E = True
        ones_F = True
        ones_G = True 

    if second_digit == 9:
        ones_A = True 
        ones_B = True
        ones_C = True
        ones_D = True
        ones_E = False 
        ones_F = True
        ones_G = True 

    if first_digit == 0:
        tens_A = True
        tens_B = True
        tens_C = False
        tens_D = True
        tens_E = True
        tens_F = True
        tens_G = False 
    
    if first_digit == 1:
        tens_A = False 
        tens_B = True
        tens_C = True
        tens_D = False
        tens_E = False
        tens_F = False
        tens_G = False 

    if first_digit == 2:
        tens_A = True 
        tens_B = True
        tens_C = False
        tens_D = True
        tens_E = True
        tens_F = False
        tens_G = True 

    if first_digit == 3:
        tens_A = True 
        tens_B = True
        tens_C = True
        tens_D = True
        tens_E = False
        tens_F = False
        tens_G = True 

    if first_digit == 4:
        tens_A = True 
        tens_B = True
        tens_C = True
        tens_D = False
        tens_E = False
        tens_F = False
        tens_G = True 

    if first_digit == 5:
        tens_A = True 
        tens_B = False
        tens_C = True
        tens_D = True
        tens_E = False
        tens_F = True
        tens_G = True 

    if first_digit == 6:
        tens_A = True 
        tens_B = False
        tens_C = True
        tens_D = True
        tens_E = True
        tens_F = True
        tens_G = True 

    if first_digit == 7:
        tens_A = True 
        tens_B = True
        tens_C = True
        tens_D = False
        tens_E = False
        tens_F = False
        tens_G = False

    if first_digit == 8:
        tens_A = True 
        tens_B = True
        tens_C = True
        tens_D = True
        tens_E = True
        tens_F = True
        tens_G = True 

    if first_digit == 9:
        tens_A = True 
        tens_B = True
        tens_C = True
        tens_D = True
        tens_E = False 
        tens_F = True
        tens_G = True 
    return

def fall_sup_check():
    """updates the LEDs of any supply centers who are ocupied by a color than what the show"""
    for i in range(len(sup_pixels)):
        # color the supply center currently is
        color = old_current_LED[i]

        # color of piece currently occupying supply center 
        piece = get_sup_piece(supply_center_TPs[i])
        
        # create a new list
        current_LED[i] = piece

        if color == piece or piece == none:
            # no ownership change, check next LED
            continue
        elif color != piece:
            # onwership has changed, set color to match
            sup_pixels[i] = piece
    return

def get_sup_piece(sup_center):
    """uses ADC to retrieve the color the piece on a supply center"""
    # returns color based on voltage, voltages are:
    # 0.000 V -> none   => no connection
    # 0.471 V -> red    => 60 kΩ 
    # 0.943 V -> green  => 25 kΩ
    # 1.414 V -> blue   => 13.4 kΩ
    # 1.886 V -> purple => 7.5 kΩ
    # 2.357 V -> yellow => 4 kΩ
    # 2.829 V -> orange => 1.7 kΩ
    # 3.300 V -> white  => 0 Ω
    # get voltage
    if sup_center == sup5 or sup_center == sup6 or sup_center == sup34:
        # AVG over time!!!
        voltage = RPv * sup_center.value * sup_center.reference_voltage
    else:
        # AVG over time!!!
        voltage = PCFv * sup_center.value * sup_center.reference_voltage

    # use voltage to get color
    if voltage < min_voltage:
        return none
    if voltage >= min_voltage and voltage < 0.707:
        return red
    if voltage >= 0.707 and voltage < 1.179:
        return green
    if voltage >= 1.179 and voltage < 1.650:
        return blue
    if voltage >= 1.650 and voltage < 2.122:
        return purple
    if voltage >= 2.122 and voltage < 2.593:
        return yellow
    if voltage >= 2.593 and voltage < 3.065:
        return orange
    if voltage >= 3.065:
        return white
    else:
        return "error"


##################################
### GLOBALS AND INITIALIZATION ###
##################################
# define RGB colors to use
# feel free to change these if you want
red = (255, 0, 15)
green = (0, 255, 0)
blue = (0, 0, 255)
purple = (255, 0, 255)
yellow = (255, 255, 0)
orange = (230, 99, 0)
# adjusted for specific LEDs
white = (200, 255, 200)
none = (0, 0, 0)

colors = [red, green, blue, purple, yellow, orange, white]

# define LED brightness, 0 -> 1 float, feel free to change
brightness = 0.1

# min
min_voltage = 0.2

# RP2040 voltage calibration factor
RPv = 1/65535

# PCF8591 voltage calibration factor
PCFv = 1/65535

# define the RGB LEDs
sup_pixels = neopixel.NeoPixel(board.GP6, 34)
season_pixels = neopixel.NeoPixel(board.GP2, 3)
sup_pixels.brightness = brightness
season_pixels.brightness = brightness

# define the buttons
next_season = digitalio.DigitalInOut(board.GP4)
next_season.switch_to_input(pull=digitalio.Pull.DOWN)

prev_season = digitalio.DigitalInOut(board.GP5)
prev_season.switch_to_input(pull=digitalio.Pull.DOWN)

restart = digitalio.DigitalInOut(board.GP3)
restart.switch_to_input(pull=digitalio.Pull.DOWN)

# define the analog pins
sup5 =  analogio.AnalogIn(board.GP26)
sup6 =  analogio.AnalogIn(board.GP27)
sup34 =  analogio.AnalogIn(board.GP28)

# set up ADCs using I2C logic pins
i2c = busio.I2C(scl=board.GP1, sda=board.GP0)

# first PCF8591 IC (top L board)
ADC_1 = PCF.PCF8591(i2c, 0x48)
sup1 = AnalogIn(ADC_1, PCF.A0)
sup2 = AnalogIn(ADC_1, PCF.A1)
sup3 = AnalogIn(ADC_1, PCF.A2)
sup4 = AnalogIn(ADC_1, PCF.A3)

# second PCF8591 IC (top R board)
ADC_2 = PCF.PCF8591(i2c, 0x49)
sup7 = AnalogIn(ADC_2, PCF.A0)
sup8 = AnalogIn(ADC_2, PCF.A1)
sup9 = AnalogIn(ADC_2, PCF.A2)

# third PCF8591 IC (bottom L board)
ADC_3 = PCF.PCF8591(i2c, 0x4A)
sup10 = AnalogIn(ADC_3, PCF.A0)
sup11 = AnalogIn(ADC_3, PCF.A1)
sup12 = AnalogIn(ADC_3, PCF.A2)
sup13 = AnalogIn(ADC_3, PCF.A3)

# forth PCF8591 IC (bottom L board)
ADC_4 = PCF.PCF8591(i2c, 0x4C)
sup14 = AnalogIn(ADC_4, PCF.A0)
sup15 = AnalogIn(ADC_4, PCF.A1)
sup16 = AnalogIn(ADC_4, PCF.A2)
sup17 = AnalogIn(ADC_4, PCF.A3)

# fifth PCF8591 IC (bottom L board)
ADC_5 = PCF.PCF8591(i2c, 0x4B)
sup18 = AnalogIn(ADC_5, PCF.A0)
sup19 = AnalogIn(ADC_5, PCF.A1)
sup20 = AnalogIn(ADC_5, PCF.A2)
sup21 = AnalogIn(ADC_5, PCF.A3)

# sixth PCF8591 IC (bottom R board)
ADC_6 = PCF.PCF8591(i2c, 0x4D)
sup22 = AnalogIn(ADC_6, PCF.A0)
sup23 = AnalogIn(ADC_6, PCF.A1)
sup24 = AnalogIn(ADC_6, PCF.A2)
sup25 = AnalogIn(ADC_6, PCF.A3)

# seventh PCF8591 IC (bottom R board)
ADC_7 = PCF.PCF8591(i2c, 0x4E)
sup26 = AnalogIn(ADC_7, PCF.A0)
sup27 = AnalogIn(ADC_7, PCF.A1)
sup28 = AnalogIn(ADC_7, PCF.A2)
sup29 = AnalogIn(ADC_7, PCF.A3)

# eighth PCF8591 IC (bottom R board)
ADC_8 = PCF.PCF8591(i2c, 0x4F)
sup30 = AnalogIn(ADC_8, PCF.A0)
sup31 = AnalogIn(ADC_8, PCF.A1)
sup32 = AnalogIn(ADC_8, PCF.A2)
sup33 = AnalogIn(ADC_8, PCF.A3)

supply_center_TPs = [sup1, sup2, sup3, sup4, sup5, sup6, sup7, sup8, sup9, sup10, sup11, sup12, sup13, sup14, sup15, sup16, sup17, sup18, sup19, sup20, sup21, sup22, sup23, sup24, sup25, sup26, sup27, sup28, sup29, sup30, sup31, sup32, sup33, sup34]

# set 7 segement display pins
tens_A = digitalio.DigitalInOut(board.GP7)
tens_A.direction = digitalio.Direction.OUTPUT

tens_B = digitalio.DigitalInOut(board.GP8)
tens_B.direction = digitalio.Direction.OUTPUT

tens_C = digitalio.DigitalInOut(board.GP9)
tens_C.direction = digitalio.Direction.OUTPUT

tens_D = digitalio.DigitalInOut(board.GP10)
tens_D.direction = digitalio.Direction.OUTPUT

tens_E = digitalio.DigitalInOut(board.GP11)
tens_E.direction = digitalio.Direction.OUTPUT

tens_F = digitalio.DigitalInOut(board.GP12)
tens_F.direction = digitalio.Direction.OUTPUT

tens_G = digitalio.DigitalInOut(board.GP13)
tens_G.direction = digitalio.Direction.OUTPUT

ones_A = digitalio.DigitalInOut(board.GP14)
ones_A.direction = digitalio.Direction.OUTPUT

ones_B = digitalio.DigitalInOut(board.GP15)
ones_B.direction = digitalio.Direction.OUTPUT

ones_C = digitalio.DigitalInOut(board.GP16)
ones_C.direction = digitalio.Direction.OUTPUT

ones_D = digitalio.DigitalInOut(board.GP17)
ones_D.direction = digitalio.Direction.OUTPUT

ones_E = digitalio.DigitalInOut(board.GP18)
ones_E.direction = digitalio.Direction.OUTPUT

ones_F = digitalio.DigitalInOut(board.GP19)
ones_F.direction = digitalio.Direction.OUTPUT

ones_G = digitalio.DigitalInOut(board.GP20)
ones_G.direction = digitalio.Direction.OUTPUT

# initalize season and year counting
# counter % 3 is the season, 1 = spring, 2 = fall, 0 = winter
# counter // 3 is the year, 0 = 1901, 1 = 1902, etc
counter = 0

# calc year and season
season = counter % 3
year = counter // 3

# initalize current color list and set all LEDs to off
sup_pixels.fill(none)
for i in range(len(sup_pixels)):
    sup_pixels[i] = colors[randrange(7)]

# current color list initiation
current_LED = []
for i in range(34):
    current_LED.append(none)

# initalize turn history
# turn history is list of lists: [[counter1, [color1, color2, color3, ...]],  [counter2, [color1, color2, color3, ...]], ... ]
history = [counter, current_LED]

# initalize toggle variable
toggle = False

led = digitalio.DigitalInOut(board.LED)
led.direction = digitalio.Direction.OUTPUT
led.value = True


#################
### MAIN LOOP ###
#################
while True:
    # set date displays
    ones = str(1901 + year)[3]
    tens = str(1901 + year)[2]
    set_7seg_disp(tens, ones)

    # set the appropriate season indicator turn off the others
    season_pixels[(season)%3] = white
    season_pixels[(season - 1)%3] = none
    season_pixels[(season - 2)%3] = none 

    # if the restart button is toggled
    if restart.value:
        # check if we've been thru this loop this toggle
        if toggle == True:
            continue

        # if first time in the loop set the toggle variable
        toggle = True

        # reset the counter (this resets the date display
        counter = 0
        season = counter % 3
        year = counter // 3

        # turn supply center LEDs off
        sup_pixels.fill(none)

        # reset the current color list
        current_LED = []
        for i in range(34):
            current_LED.append(none)

        # clear and reset the turn history list
        history = [] 
        history = [counter, current_LED]

        # ignore any coincidental press of next and prev
        continue

    # if the next button is toggled
    if next_season.value:
        # check if we've been thru this loop this toggle
        if toggle == True:
            continue

        # if first time in the loop set the toggle variable
        toggle = True

        # increment the season
        counter = counter + 1
        season = counter % 3
        year = counter // 3
        
        # if we are moving fall -> winter
        if season == 2:
            old_current_LED = current_LED

            # check supply centers to see if their ownership has changed
            fall_sup_check()

            # add old current list to history
            history.append([counter, old_current_LED])

        # ignore any coincidental press of prev
        continue
            
    # if the previous button is toggled
    if prev_season.value:
        # check if we've been thru this loop this toggle
        if toggle == True:
            continue

        # if first time in the loop set the toggle variable
        toggle = True

        # decrement the season
        counter = counter - 1
        season = counter % 3
        year = counter // 3

        # check to see if we need to regress the supply centers 
        if season == 1:
            # then get the supply center colors for this value in the list
            for i in range(len(history[-1][1])):
                sup_pixels[i] = history[-1][1][i]

            # now remove this value from history
            history.pop()
        continue

    # if no button is depressed
    else:
        toggle = False
        

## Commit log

2022-05-28 combined all boards into one kicad PCB to render together
    [full_board.kicad_pcb]
2022-05-28 added BoM
    [top_L.kicad_pcb]
2022-05-28 edit BoM
2022-05-29 added some cutouts from another project to the stencil
    [stencil.kicad_pcb]
